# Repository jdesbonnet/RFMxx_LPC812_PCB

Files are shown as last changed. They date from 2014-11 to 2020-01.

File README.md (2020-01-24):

# RFM69HW and RFM98W experimentation board with option for LPC812/LPC824 MCU

This is a PCB board to experiment with HopeRF RFM69HW and RFM98 radio modules (or any modules in that family with a compatible footprint). 

The module can be accessed directly throught JP1 which breaks out the modules SPI bus and a few other pins.

Alternatively a LPC812 (ARM Cortex-M0+ MCU) can be soldered on the board as a controller. Firmware for the LPC812 is here: https://github.com/jdesbonnet/RFM69_LPC812_firmware

There is a blog post discussing this in more detail here: 
http://jdesbonnet.blogspot.ie/2014/12/experiments-with-rfm69-433mhz-digital.html

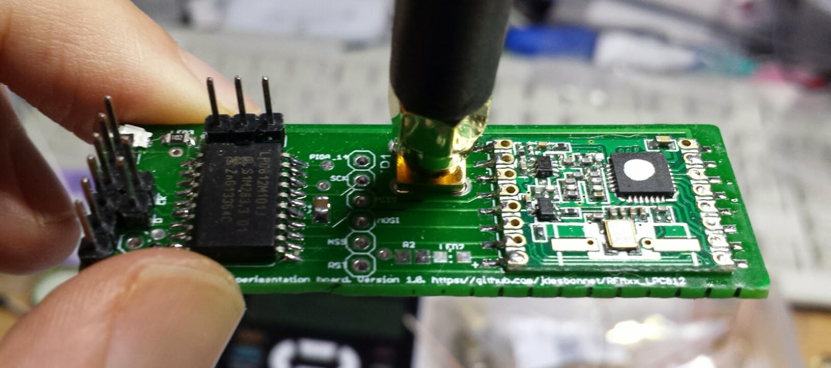
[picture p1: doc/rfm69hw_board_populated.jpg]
populated RFM69HW version of the PCB


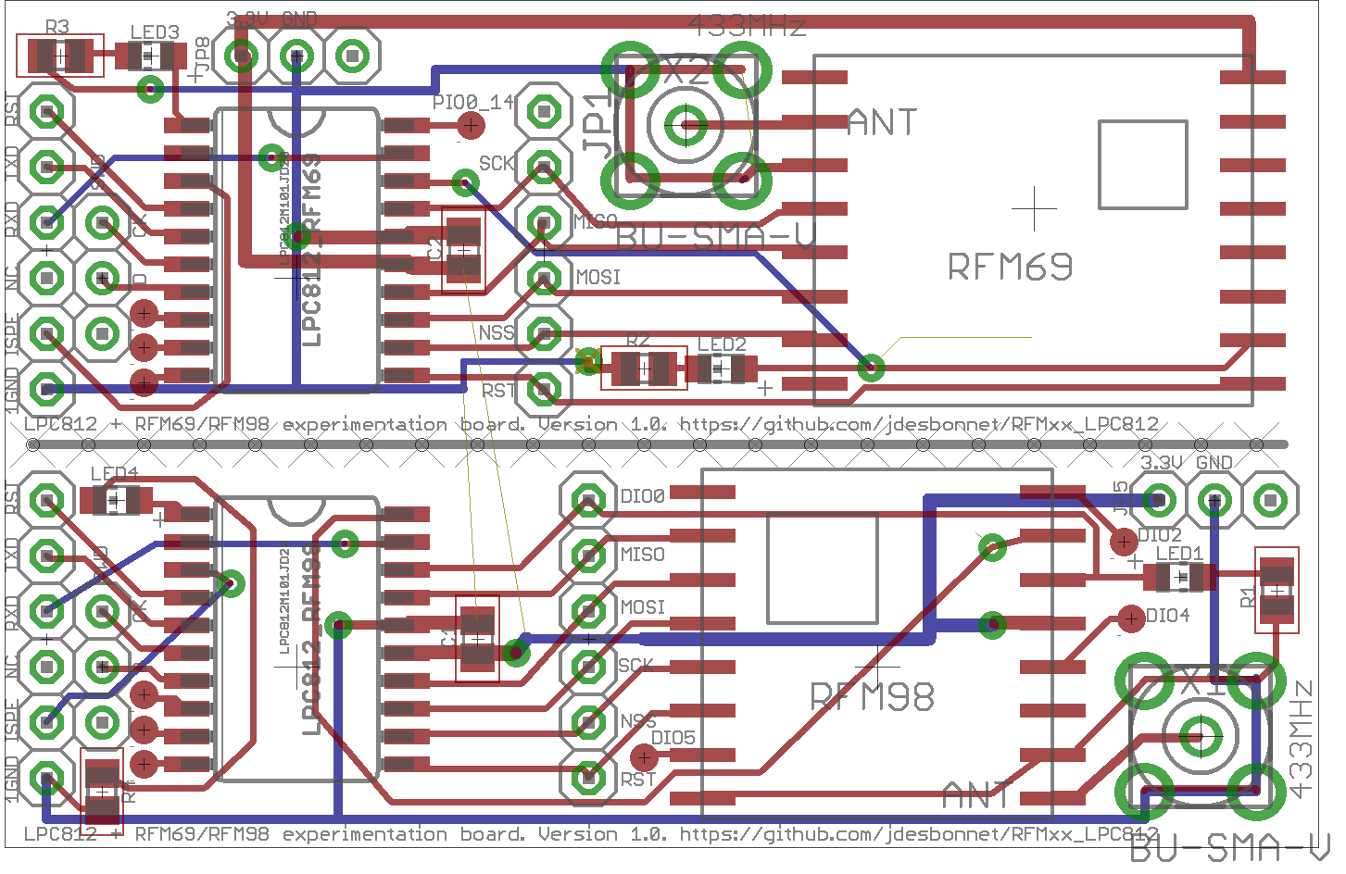
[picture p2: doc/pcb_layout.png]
PCB layout


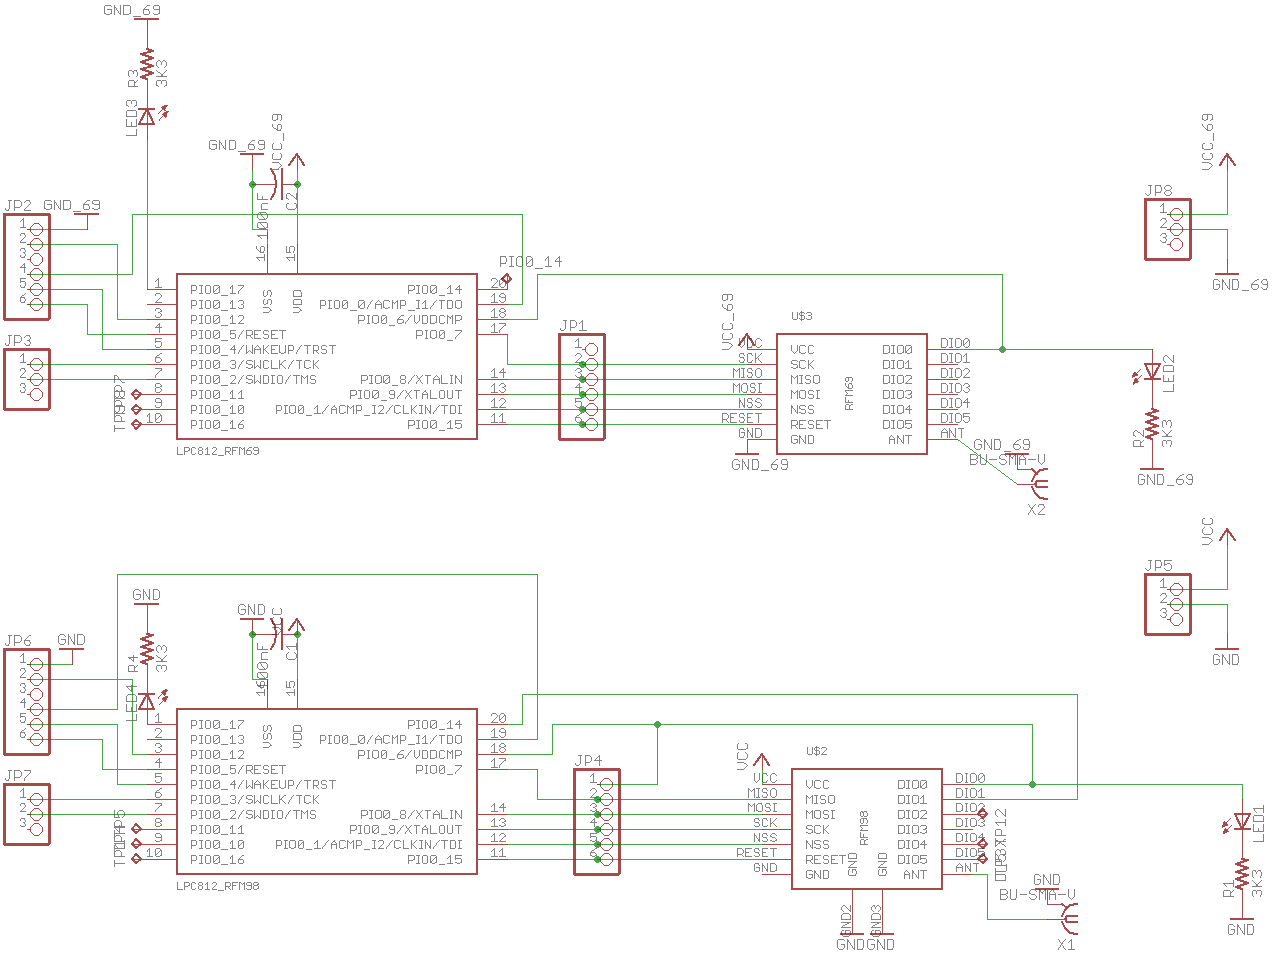
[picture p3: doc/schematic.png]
schematic


# Pinout

## Common to RFM69 and RFM98 boards

Leftmost column of 6 pins (from top to bottom): RESET, UART_TXD, UART_RXD, NC, ISP_ENTRY, GND.

Second column from left of 3 pins (from top to bottom): SWD_CLOCK, SWD_DATA, NC.

## RFM69
Three pin row above MCU (from left to right): 3.3V, GND, NC.

## RFM98 
Three pin row at top-right corner of the board (from left to right):  3.3V, GND, NC.

NC: not connect. SWD: serial wire debug. 

# Lessons from first iteration of PCB
 * Keep spacing of headers and test pads snapped to 0.1in grid to facilitate easy construction of bed of nails test rig on proto board.
 * Include power and ground on all headers even if it duplicates.
 * For traces that may become optional use 0 ohm jumper resistors to complete link, or use test pads to allow easy reconnection if a trace needs to be cut (undoing a manually cut trace is a pain).
 * Choice of font on v1 board was too small.
 * Consider side SMA connector
 
 # Version 2 PCB using LPC824
 
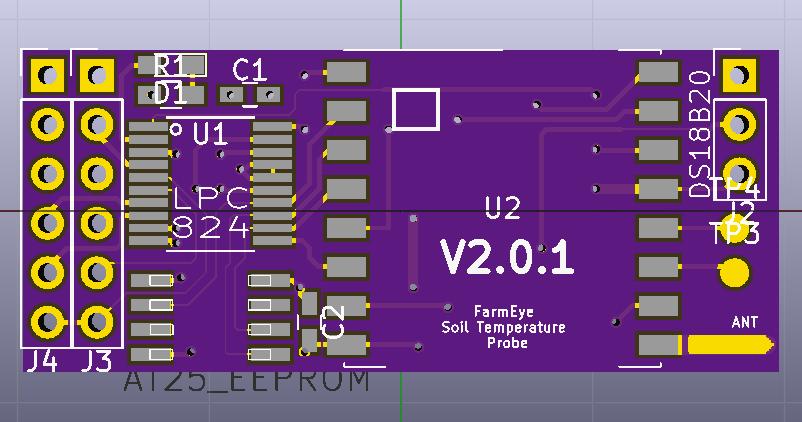
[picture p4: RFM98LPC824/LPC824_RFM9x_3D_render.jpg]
3D rendering of v2.0.x PCB
 

[Version 2 project files](./RFM98LPC824)

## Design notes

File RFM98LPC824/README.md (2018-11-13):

# LPC/RFM radio board version 2

The V2 series replaces the LPC812 with LP824, and adds a SPI flash
IC. 

3D rendering of v2.0.x PCB

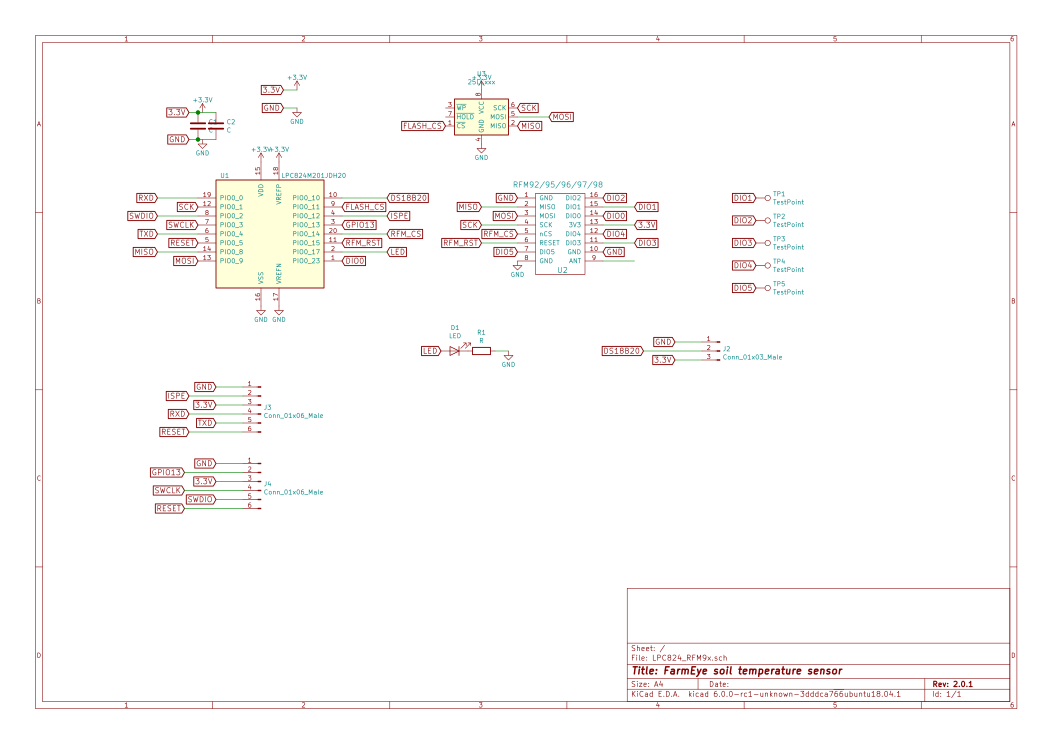
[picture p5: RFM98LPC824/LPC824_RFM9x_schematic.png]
Schematic


## V2.0.0 2018-04-14

Improvement on 2014 design: more compact board.

## V2.0.1 2018-04-15

 * Fix missing RFM_CS trace and remove TP for GPIO14 which now has that function. 
 * Minor track layout change to space flash MISO line further from flash MOSI.

V2.0.1 board arrived back from OSHPark on 2018-05-11.

## Header pinouts

(from top to bottom in the redering above)

J3: GND, ISPE, 3.3V, RXD, TXD, RESET

J4: GND, GPIO13, 3.3V, SWCLK, SWDIO, RESET

## Hardware notes:

SPI bus is shared with RFM module and flash IC. Flash IC is 25P16 (or any SPI flash with similar pinout).

| Function | Pin |  |
|---|---|--|
| FLASH_CS | PIO0_11 | This is a hardware bug: PIO0_11 is open drain: cannot drive high w/o external pullup R |
| MOSI | PIO0_9  |  |
| MISO | PIO0_8  |  |
| SCK | PIO0_1  |  |
| RFM_CS | PIO0_14 |  |
| RFM_RST  | PIO0_15 |  |
| LED | PIO0_17 |  |
| RFM_DIO0 | PIO0_23 |  |
| DS18B20  | PIO0_10 |  |

Temporary fix for FLASH_CS bug is to route GPIO0_13 from J4 with bodge wire. An alternative approach would be to glue SMD R for pull up to back of PCB. Will shuffle the pins in next PCB to that PIO0_11 is used only for input. Also may have problem with PIO0_10 used for the DS18B20.

DS18B20 confirmed to work. A 0603 4.7K SMD R is soldered between the 3.3V and data on J2. 0603 is about the perfect size for that hack. Unclear if this will have any impact of the deep sleep current consumption.

The external flash IC chosen has a deep-sleep current much larger than what can be achieved with the LPC824 on its own. Seeing something in the order of 20µA (vs 3µA from LPC824 in powerdown). However there are parts which claim much better deep sleep performance eg Macronix MX25R6435F which is pin compatible. http://www.macronix.com/en-us/products/NOR-Flash/Pages/Ultra-Low-Power-Flash.aspx

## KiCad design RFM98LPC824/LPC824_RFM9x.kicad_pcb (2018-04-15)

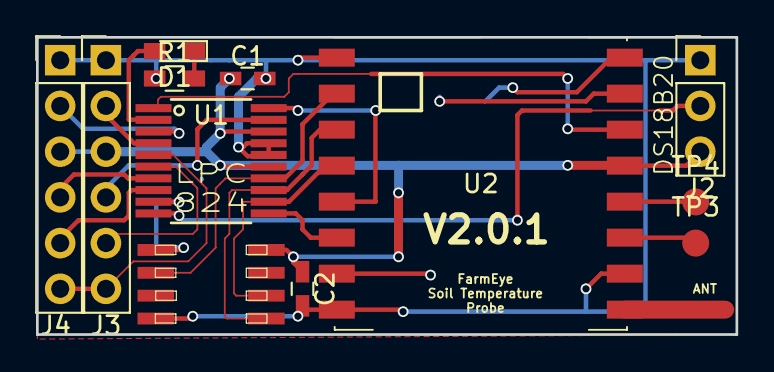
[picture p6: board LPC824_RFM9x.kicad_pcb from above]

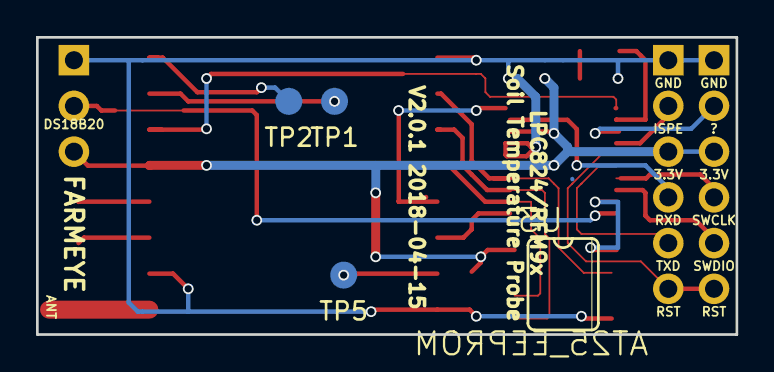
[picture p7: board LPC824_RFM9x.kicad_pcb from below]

Board: 2 copper layers, 38.9 x 16.5 mm, 15 parts (3 on the bottom side), 24 nets.

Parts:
C1, C2: C; C_0603_HandSoldering
D1: LED; LED_0603_HandSoldering
J2: Conn_01x03; Pin_Header_Straight_1x03_Pitch2.54mm
J3, J4: Conn_01x06; Pin_Header_Straight_1x06_Pitch2.54mm
R1: R; R_0603_HandSoldering
TP1, TP2, TP3, TP4, TP5: TEST; Measurement_Point_Round-SMD-Pad_Small
U1: LPC824M201JDH20; TSSOP-20_4.4x6.5mm_Pitch0.65mm
U2: RFM92/95/96/97/98; Hopref_RFM9XW_SMD
U3: AT25_EEPROM; SO08

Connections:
3.3V: C1.1, C2.1, J2.3, J3.3, J4.3, U1.15, U1.18, U2.13, U3.8
DIO0: U1.1, U2.14
DIO1: TP1.1, U2.15
DIO2: TP2.1, U2.16
DIO3: TP3.1, U2.11
DIO4: TP4.1, U2.12
DIO5: TP5.1, U2.7
DS18B20: J2.2, U1.10
FLASH_CS: U1.9, U3.1
GND: C1.2, C2.2, J2.1, J3.1, J4.1, R1.1, U1.16, U1.17, U2.1, U2.8, U2.10, U3.4
GPIO13: J4.2, U1.3
ISPE: J3.2, U1.4
LED: D1.2, U1.2
MISO: U1.14, U2.2, U3.2
MOSI: U1.13, U2.3, U3.5
unnamed: D1.1, R1.2
RESET: J3.6, J4.6, U1.5
RFM_CS: U1.20, U2.5
RFM_RST: U1.11, U2.6
RXD: J3.4, U1.19
SCK: U1.12, U2.4, U3.6
SWCLK: J4.4, U1.7
SWDIO: J4.5, U1.8
TXD: J3.5, U1.6

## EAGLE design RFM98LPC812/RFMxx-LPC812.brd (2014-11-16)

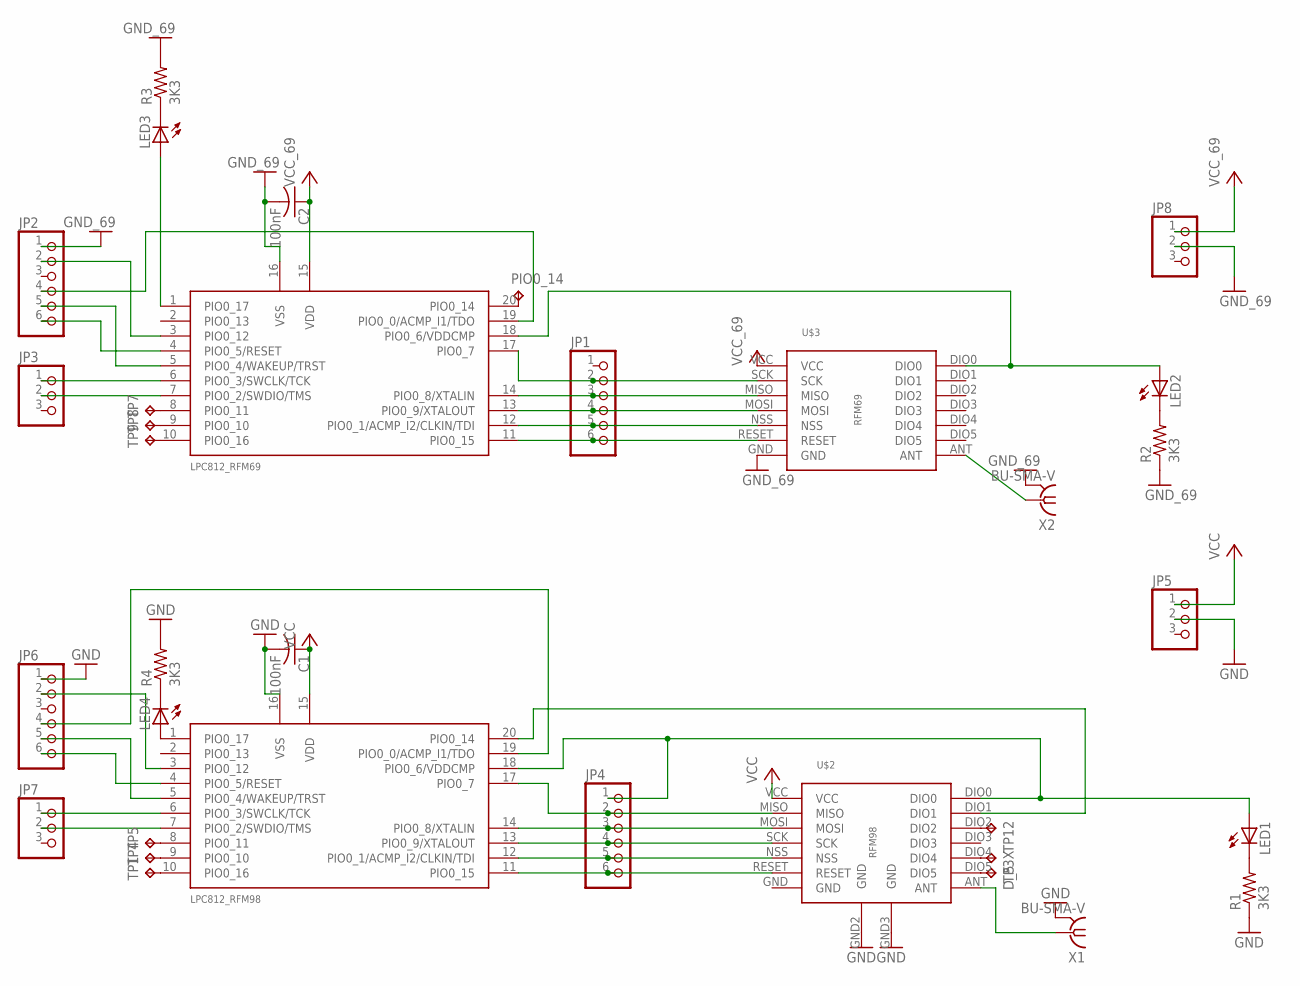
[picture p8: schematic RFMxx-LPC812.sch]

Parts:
C1, C2: 100nF; C0805
D_5: TPB1,27; B1,27
JP1, JP2, JP4, JP6: PINHD-1X6; 1X06
JP3, JP5, JP7, JP8: PINHD-1X3; 1X03
LED1, LED2, LED3, LED4: LEDCHIP-LED0805; CHIP-LED0805
LPC812_RFM69, LPC812_RFM98: LPC812M101JD20; SOIC20
PIO0_14: TPB1,27; B1,27
R1, R2, R3, R4: 3K3; R0805
TP1, TP3X, TP4, TP5, TP7, TP8, TP9, TP12: TPB1,27; B1,27
U$2: RFM98W; RFM98_PADS
U$3: RFM69HW; RFM69_PADS
X1, X2: BU-SMA-V

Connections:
GND: C1.2, C2.2, JP2.1, JP5.2, JP6.1, JP8.2, LPC812_RFM69.16 (VSS), LPC812_RFM98.16 (VSS), R1.1, R2.1, R3.2, R4.2, U$2.GND2 (GND), U$2.GND3 (GND), U$3.GND, X1.2, X1.3 (2), X1.4 (2), X1.5 (2), X2.2, X2.3 (2), X2.4 (2), X2.5 (2)
unnamed: U$3.ANT, X2.1
unnamed: JP2.5, LPC812_RFM69.5 (PIO0_4/WAKEUP/TRST)
unnamed: JP3.1, LPC812_RFM69.6 (PIO0_3/SWCLK/TCK)
unnamed: JP2.2, LPC812_RFM69.3 (PIO0_12)
unnamed: JP2.6, LPC812_RFM69.4 (PIO0_5/RESET)
unnamed: U$2.ANT, X1.1
unnamed: JP4.5, LPC812_RFM98.12 (PIO0_1/ACMP_I2/CLKIN/TDI), U$2.NSS
unnamed: JP4.3, LPC812_RFM98.14 (PIO0_8/XTALIN), U$2.MOSI
unnamed: JP4.4, LPC812_RFM98.13 (PIO0_9/XTALOUT), U$2.SCK
unnamed: JP4.2, LPC812_RFM98.17 (PIO0_7), U$2.MISO
unnamed: JP4.6, LPC812_RFM98.11 (PIO0_15), U$2.RESET
unnamed: JP1.6, LPC812_RFM69.11 (PIO0_15), U$3.RESET
unnamed: JP1.5, LPC812_RFM69.12 (PIO0_1/ACMP_I2/CLKIN/TDI), U$3.NSS
unnamed: JP1.4, LPC812_RFM69.13 (PIO0_9/XTALOUT), U$3.MOSI
unnamed: JP1.3, LPC812_RFM69.14 (PIO0_8/XTALIN), U$3.MISO
unnamed: JP6.6, LPC812_RFM98.4 (PIO0_5/RESET)
unnamed: JP6.5, LPC812_RFM98.5 (PIO0_4/WAKEUP/TRST)
unnamed: JP1.2, LPC812_RFM69.17 (PIO0_7), U$3.SCK
unnamed: JP6.4, LPC812_RFM98.19 (PIO0_0/ACMP_I1/TDO)
unnamed: JP6.2, LPC812_RFM98.3 (PIO0_12)
unnamed: JP4.1, LED1.A, LPC812_RFM98.18 (PIO0_6/VDDCMP), U$2.DIO0
unnamed: JP3.2, LPC812_RFM69.7 (PIO0_2/SWDIO/TMS)
unnamed: LED2.A, LPC812_RFM69.18 (PIO0_6/VDDCMP), U$3.DIO0
unnamed: LPC812_RFM98.10 (PIO0_16), TP1.TP
unnamed: LED4.A, LPC812_RFM98.1 (PIO0_17)
unnamed: LPC812_RFM98.20 (PIO0_14), U$2.DIO1
unnamed: JP7.1, LPC812_RFM98.6 (PIO0_3/SWCLK/TCK)
unnamed: JP7.2, LPC812_RFM98.7 (PIO0_2/SWDIO/TMS)
unnamed: TP3X.TP, U$2.DIO4
unnamed: LPC812_RFM98.9 (PIO0_10), TP4.TP
unnamed: LPC812_RFM98.8 (PIO0_11), TP5.TP
unnamed: D_5.TP, U$2.DIO5
unnamed: JP2.4, LPC812_RFM69.19 (PIO0_0/ACMP_I1/TDO)
unnamed: LED3.A, LPC812_RFM69.1 (PIO0_17)
unnamed: LED1.C, R1.2
unnamed: LED2.C, R2.2
unnamed: LED3.C, R3.1
unnamed: LPC812_RFM69.8 (PIO0_11), TP7.TP
unnamed: LED4.C, R4.1
unnamed: LPC812_RFM69.9 (PIO0_10), TP8.TP
unnamed: LPC812_RFM69.10 (PIO0_16), TP9.TP
unnamed: LPC812_RFM69.20 (PIO0_14), PIO0_14.TP
unnamed: TP12.TP, U$2.DIO2
VCC: C1.1, C2.1, JP5.1, JP8.1, LPC812_RFM69.15 (VDD), LPC812_RFM98.15 (VDD), U$2.VCC, U$3.VCC

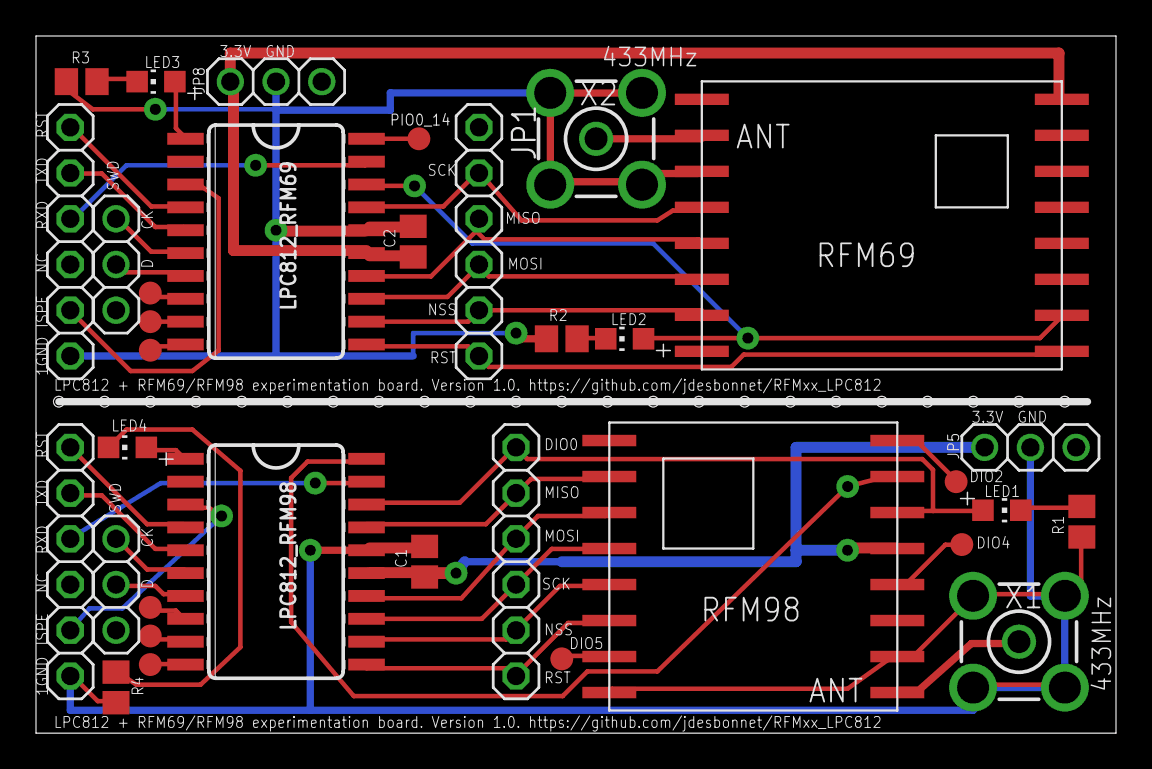
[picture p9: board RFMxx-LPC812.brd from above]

Board: 2 copper layers, 60.0 x 38.7 mm, 34 parts (0 on the bottom side), 45 nets.

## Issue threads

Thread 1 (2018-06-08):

Use PullUps for NSS, MOSI, SCK

JojoS62, 2018-06-08:
nice board. I've built a similiar one, also with LPC812 and RFM69. I'm using it for some sensors in homeautomation.
For maximum power saving in deep power down mode, I found that it is necessary to add external pull up resistors of about 47k to prevent the RFM inputs from floating. Without these resistors the idle current was much higher as stated in the datasheet.

jdesbonnet, 2018-06-08:
What kind of sleep current are you getting? I think I got mine down to 4uA with the wake-up timer running. Getting it down to that level involved some experimentation with the pin states. I'd be curious to know if you did better?

JojoS62, 2018-06-08:
the wake up timer takes about 1 µA, in total I have 1,3 µA for the LPC812 with self wake up, RFM and a SHT31 temp/moisture sensor. Without self wake up it uses about 0,3 µA.

jdesbonnet, 2018-06-08:
Thanks for the tips. I must try get that 4uA down further.

JojoS62, 2018-06-08:
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
you're welcome. On your board, you have some headers for testing, thats fine. I had to add some tombstones to fix it :)
I'm preparing my software also for releasing on Github, great to find someone not only using AVRs :)

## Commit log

2014-11-03 Add RFM69HW device
2014-11-04 first commit of RFMxx board
    [RFMxx-LPC812.brd, RFMxx-LPC812.sch]
2014-11-04 no comment
    [RFMxx-LPC812.brd, RFMxx-LPC812.sch]
2014-11-05 reasonably good layout on RFM98 side
    [RFMxx-LPC812.brd, RFMxx-LPC812.sch]
2014-11-05 start working on RFM69
    [RFMxx-LPC812.brd, RFMxx-LPC812.sch]
2014-11-05 start removing ground plane on RFM98 side
    [RFMxx-LPC812.brd, RFMxx-LPC812.sch]
2014-11-06 LEDs on DIO0
    [RFMxx-LPC812.brd, RFMxx-LPC812.sch]
2014-11-06 trace bug fixes
    [RFMxx-LPC812.brd, RFMxx-LPC812.sch]
2014-11-06 attempting to separate vcc, gnd on both sides of the board
    [RFMxx-LPC812.brd]
2014-11-06 getting close to done
    [RFMxx-LPC812.brd, RFMxx-LPC812.sch]
2014-11-07 fixed inconsistency by hand editing .brd XML
    [RFMxx-LPC812.brd]
2014-11-07 added TPs for DIO0..5 on RFM69 side
    [RFMxx-LPC812.brd, RFMxx-LPC812.sch]
2014-11-07 better routing of power to RFM98
    [RFMxx-LPC812.brd]
2014-11-07 some refinements
    [RFMxx-LPC812.brd, RFMxx-LPC812.sch]
2014-11-07 some tidyup before Rev 1
    [RFMxx-LPC812.brd]
2014-11-07 Remove markings from bottom of board. Failed to reduce quote, so must be the TPs.
    [RFMxx-LPC812.brd]
2014-11-08 Removed TPs, now quote back down to the EUR 85 level.
    [RFMxx-LPC812.brd, RFMxx-LPC812.sch]
2014-11-08 fix some clearance issues which is pushing up the price due to using thinner copper foil
    [RFMxx-LPC812.brd, RFMxx-LPC812.sch]
2014-11-08 increase dia of vias: this finally brings the Eurocircuits quote back down to the same level as an earlier version of the board.
    [RFMxx-LPC812.brd]
2014-11-08 cosmetic changes to board lables
    [RFMxx-LPC812.brd]
2014-11-08 label cosmetic changes
    [RFMxx-LPC812.brd]
2014-11-08 more cosmetic changes
    [RFMxx-LPC812.brd]
2014-11-08 extra holes on dividing line
    [RFMxx-LPC812.brd]
2014-11-16 Via between RXD on UART connector to PIO0_0 was too close to 3.3V line and merged in V1 of PCB. Move via.
    [RFMxx-LPC812.brd]
2016-04-24 photo of populated RFM69HW board
2016-08-14 add PCB layout image
2016-08-14 add image of schematic
2018-04-14 v2.0.0 schematic and layout
    [LPC824_RFM9x.kicad_pcb, LPC824_RFM9x.sch]
2018-04-14 move SPI flash MISO trace away from MOSI
    [LPC824_RFM9x.kicad_pcb]
2018-04-15 gerber file sent to OSHPark
2018-04-15 add missing RFM_CS trace
    [LPC824_RFM9x.kicad_pcb, LPC824_RFM9x.sch]
2018-04-15 add GPIO11 test pad
    [LPC824_RFM9x.kicad_pcb, LPC824_RFM9x.sch]
2018-04-15 RFM9x breakout
    [RFM9x_breakout.kicad_pcb, RFM9x_breakout.sch]
2018-04-15 move RFM9x_breakout to separate github repo
    [RFM9x_breakout.kicad_pcb, RFM9x_breakout.sch]
2018-04-15 hand solder friendly pads (extended length)
2018-04-15 LPC824/RFM9x board v2.0.1
    [LPC824_RFM9x.kicad_pcb, LPC824_RFM9x.sch]
2018-11-11 kicad 6.0
    [LPC824_RFM9x.sch]
